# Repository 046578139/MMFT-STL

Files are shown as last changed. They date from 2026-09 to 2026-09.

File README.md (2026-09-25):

# MMFT-STL

3D-printable models for **Mountain Maryland Firearms Training**.

## Pistol display stand

A counter-top display stand: a filleted base plate with a leaning
magazine-well blade at one end and the MMFT mark standing proud of the plate
in front of it. Designed to print in a black body with the mark in red.

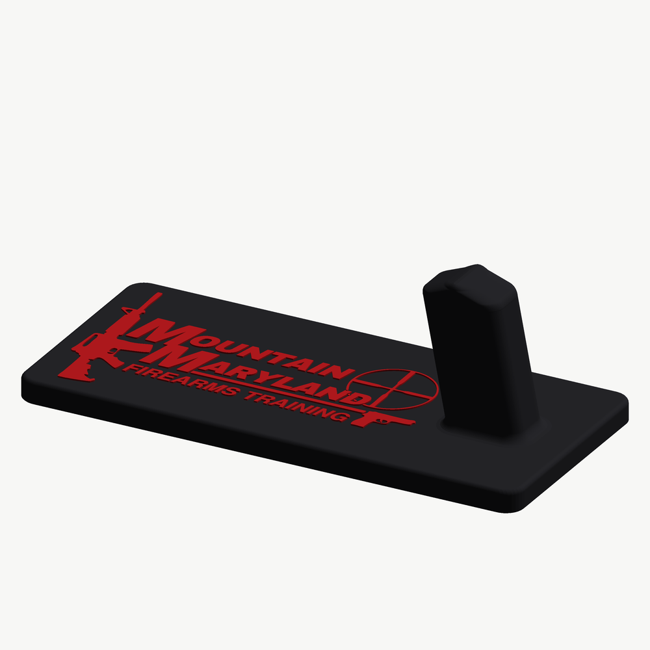
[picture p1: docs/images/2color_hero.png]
The stand in black with a red mark


| | |
|---|---|
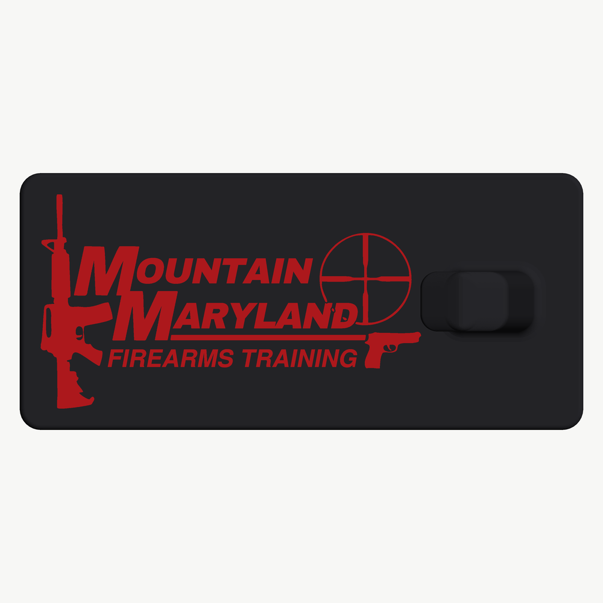
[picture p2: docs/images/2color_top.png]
top
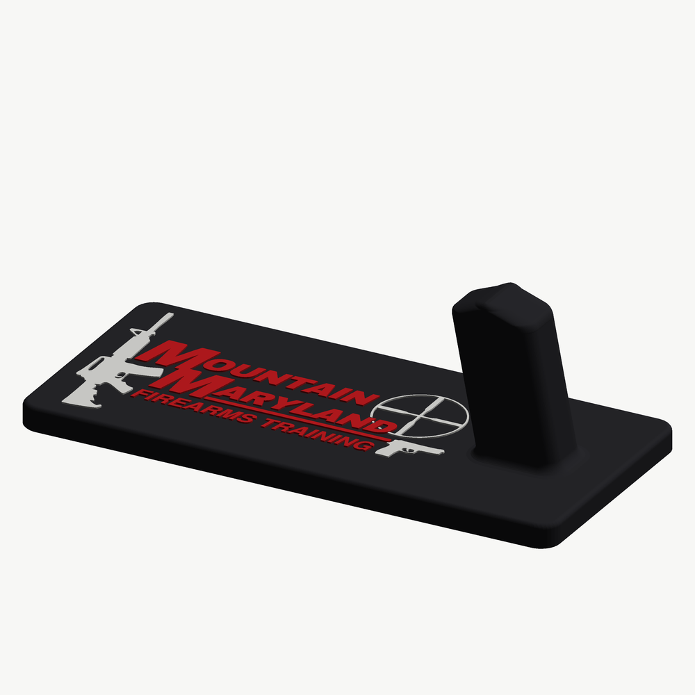
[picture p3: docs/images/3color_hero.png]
three colour
|  |  |
| Two colours — black and red | Three colours — see note below on which way round |

**215 × 98 × 70.6 mm.** No supports, no bridging, flat on the plate.

Sized up from an earlier 160 × 70 after a test print: at that size the gaps
*between* the letters were narrower than a nozzle could lay a bead into, so
they filled in and the lettering came out ragged. The mark is now 145 mm
wide instead of 90, and the narrowest gap in it is 0.460 mm.

**Print it with a 0.4 mm nozzle.** That number is why: a 0.6 mm nozzle lays
a bead wider than the gap and fuses four separate pieces of the mark into
one blob, and no slicer setting can undo it.

One thing to know before these go on a counter: the stand is enormously
stronger than it needs to be, but it tips sideways at about 0.65 lbf, and
**infill does not fix that** — see
[Will it stay put](docs/PRINTING.md#will-it-stay-put).

### Raised or flush

The mark comes two ways. Both look the same from straight on; they differ
in whether it stands on the plate or is let into it.

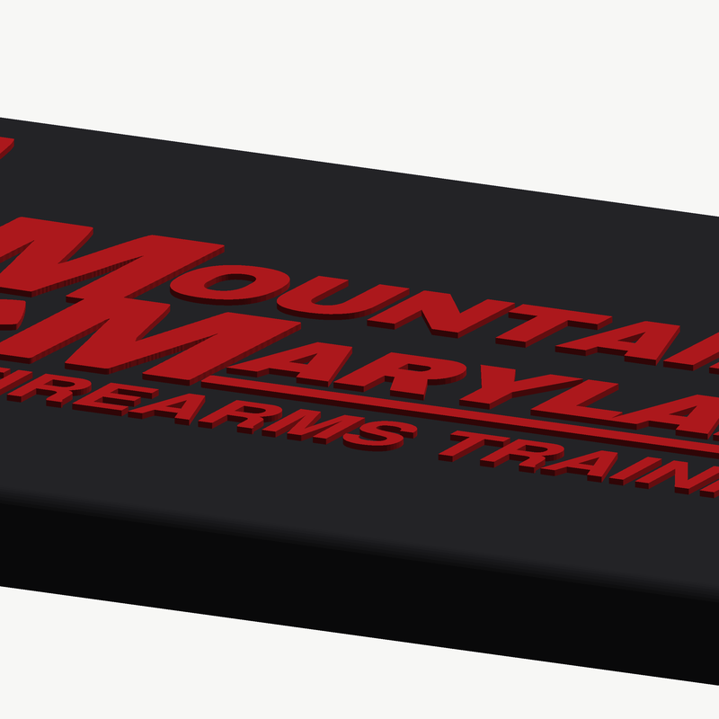
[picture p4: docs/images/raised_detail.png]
raised
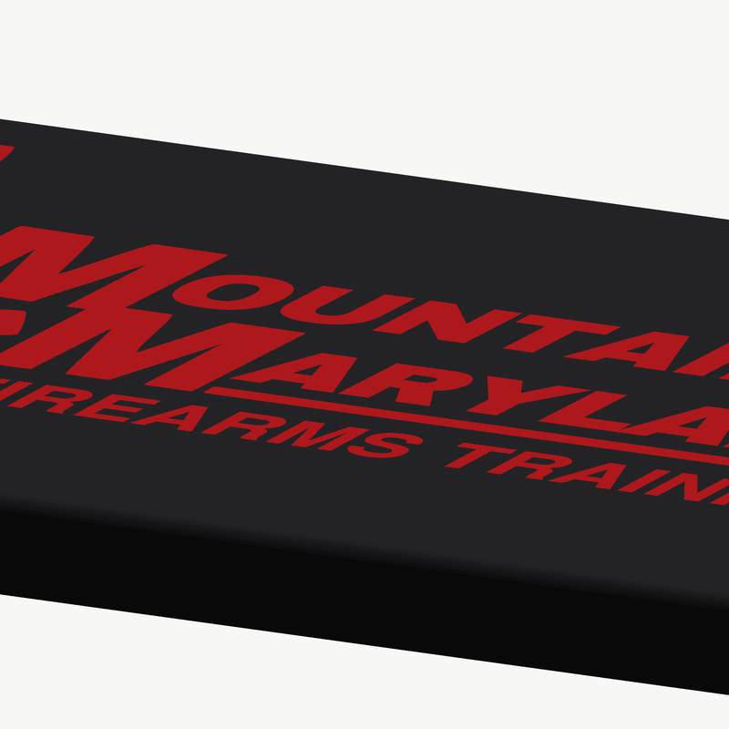
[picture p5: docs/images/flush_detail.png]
flush
|  |  |
|---|---|
| **`stl/raised/`** — stands 0.6 mm proud | **`stl/flush/`** — let 0.6 mm into the plate |

**Flush is the one to print for a shop counter.** Nothing stands above the
surface to be caught or chipped, and every piece of the mark is boxed in on
all four sides by the black around it — a muzzle dragged across it just
slides. It needs a multi-material printer, because black and red share the
same three layers.

**Raised** is there because it prints in two colours on *any* printer. Every
layer above the plate is mark and nothing else, so a single extruder only
needs a filament change at Z = 9.6 mm and another at Z = 10.2 mm. The
trade-off is that two pieces are small — the slivers of the scope's
crosshair showing through "ND", at 0.71 and 1.02 mm², which is not much
holding a 0.6 mm tall nub. Everything else is far sturdier since the mark
was scaled up; the smallest piece of lettering is now 9.6 mm².

### One file, or several

**`3mf/` holds the whole model as a single file per variant** — parts kept
together, colours already set, nothing to line up. Open one and print:

| File | Parts |
|---|---|
| `3mf/MMFT_Stand_flush_2color.3mf` | black body + red mark |
| `3mf/MMFT_Stand_flush_3color.3mf` | black body + red lettering + bone firearms |
| `3mf/MMFT_Stand_raised_2color.3mf` | black body + red mark |
| `3mf/MMFT_Stand_raised_3color.3mf` | black body + red lettering + bone firearms |

**This cannot be done as an STL.** An STL file is a bare list of triangles
with no notion of colour, material, or even where one body ends and the next
begins — so a two-colour model has to travel as two STLs and be lined up
again at the other end. 3MF is the format that fixes exactly that, and every
current slicer reads it. As a bonus the whole two-colour project is 0.65 MB
against 3.4 MB for the equivalent pair of STLs.

Inside, the parts are written as *components of one object* rather than as
separate objects side by side. That matters: as separate objects a slicer is
free to move them independently, and a single auto-arrange would slide the
mark off the plate it belongs to. As components they move together and
cannot come apart.

Colours are carried twice — `<basematerials>`, which is the core 3MF way any
slicer reads, and `Metadata/model_settings.config`, the Bambu Studio and
Orca convention where each part names the filament slot it wants. If your
slicer understands neither, you still get the geometry and the separate
parts, and assigning the filaments by hand is a couple of clicks.

Bambu Studio greets any non-Bambu 3MF with *"The 3mf file has invalid
config, load geometry data only"*. That is about the print profile, not the
model, and these files carry no print profile on purpose — see
[docs/PRINTING.md](docs/PRINTING.md).

### STL files

Still here for anything that will not take a 3MF, and for single-colour
prints where one body is all you need.

| File | Colour | Set |
|---|---|---|
| `raised/MMFT_Stand_black_body.stl` | black | 2- and 3-colour |
| `raised/MMFT_Stand_red_logo_full.stl` | red | 2-colour |
| `raised/MMFT_Stand_red_logo_text.stl` | the lettering | 3-colour |
| `raised/MMFT_Stand_light_logo_art.stl` | the firearms | 3-colour |
| `raised/MMFT_Stand_one_piece.stl` | any single colour | on its own |
| `flush/MMFT_Stand_black_body.stl` | black | 2- and 3-colour |
| `flush/MMFT_Stand_red_logo_full.stl` | red | 2-colour |
| `flush/MMFT_Stand_red_logo_text.stl` | the lettering | 3-colour |
| `flush/MMFT_Stand_light_logo_art.stl` | the firearms | 3-colour |
| `flush/MMFT_Stand_engraved_one_piece.stl` | any single colour | on its own |

Every part is modelled in the same coordinate space, so a multi-material
slicer only needs them loaded together and assigned colours — there is
nothing to line up by hand. The flush body and its inlay reassemble into the
solid plate to within a hundred-thousandth of a cubic millimetre, with no
overlap for a slicer to argue with.

`flush/MMFT_Stand_engraved_one_piece.stl` is the flush plate with its
pockets left empty — one colour, nothing proud of the surface at all. The
engraved channels are comfortably printable (the thinnest is 1.72 mm); what
is marginal is the ribs of plate left standing *between* them, the narrowest
of which is 0.46 mm — about one bead wide, so a few will look soft. The
lettering comes through cleanly.

See [docs/PRINTING.md](docs/PRINTING.md) for settings and filament choice.

### How crisp is the mark?

It is traced as vector outlines, not stamped from pixels — straight edges
come out exactly straight (the rule under the wordmark is two points across
46 mm) and the scope ring is round to 0.026 mm RMS, about a fifteenth of an
extrusion width. Nothing in the geometry is stepped.

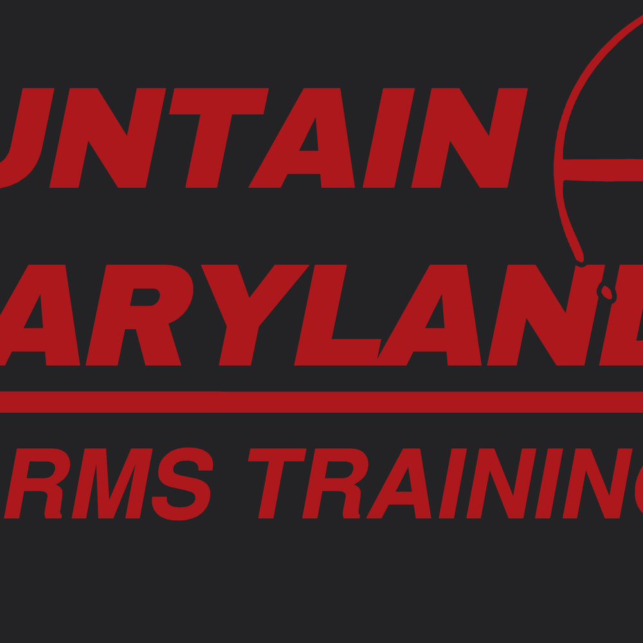
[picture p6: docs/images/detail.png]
detail


The preview images are rendered at a size where one pixel is roughly 0.2 mm
of real part, so curves in them can look stepped when the model is not.
`src/preview.py` supersamples to keep that under control.

### The lettering

Two runs in the mark are too small in the source to trace well, for a
reason no amount of work on the tracer can fix. "FIREARMS TRAINING" is
about **34 px** of cap height in the file, and the small caps of the
wordmark about **47 px**. There is no detail there to recover.

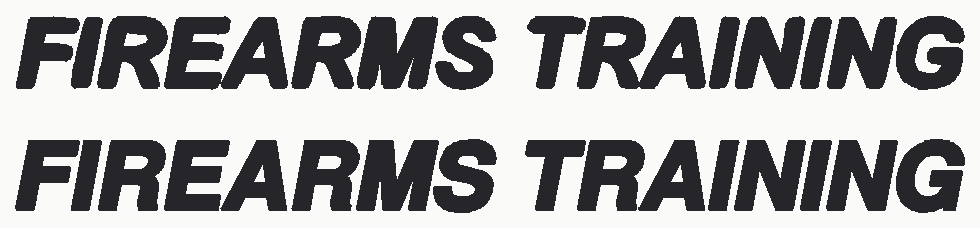
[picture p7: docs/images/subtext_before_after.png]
sub-text, before and after


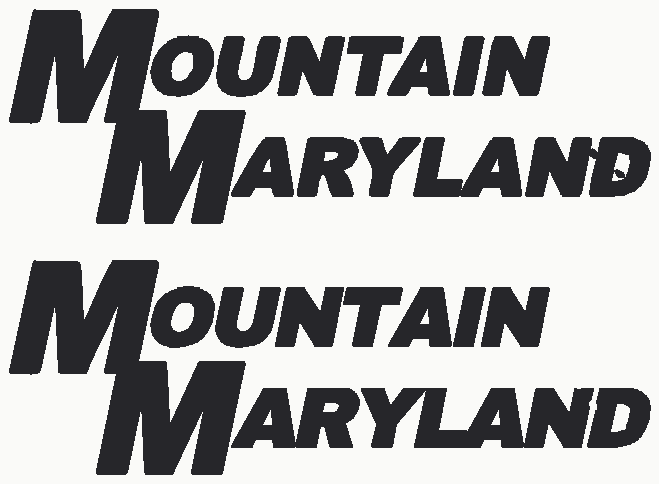
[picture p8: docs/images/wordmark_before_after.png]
wordmark, before and after


*Each pair: traced from the raster, then set from type.*

Both are re-set from outlines instead. Each run was matched the same way —
normalise cap height, solve tracking to match the run's width, score pixel
overlap against the source — then fitted to the box the traced run
occupied, so everything lands where the artwork puts it.

**They are not the same typeface, and that turns out to be the point.**
Stroke-to-cap comes out at 0.176 for the sub-text and 0.265 for the
wordmark: the mark pairs a Bold with a Black. Setting both in one weight
would have flattened that, so each is matched on its own.

| Run | Candidate | Overlap |
|---|---|---|
| Sub-text | **FreeSans Bold Oblique** (Helvetica clone) | **0.871** |
| | Nimbus Sans Bold Italic (Helvetica clone) | 0.870 |
| | Arial metrics (Liberation Sans Bold Italic) | 0.791 |
| Wordmark | **Archivo Black**, condensed 3 % | **0.895** |
| | Archivo weight 900 | 0.870 |
| | Asap weight 900 | 0.865 |
| | any Bold weight | below 0.69 |

The sub-text is Helvetica, near enough. The wordmark is a heavy grotesque
that Archivo Black stands in for: every letter traces 4–7 % narrower than
Archivo draws it, so the original is the narrower face of the two, and
condensing Archivo by 3 % both improves the match and brings the tracking
needed to fill the line back near zero, where the letters stop colliding.

Weight is preserved in both — the sub-text comes out at 1.08 mm median
stroke against the traced 1.05 mm. Only the edges change.

**The two large M's are left as traced.** They are 177 px in the source,
clean enough that setting them would gain nothing, and they are a drawn
lockup rather than two letters set side by side — re-setting them would
have broken the way they interlock.

**If you have the original vector logo** (`.ai`, `.eps`, `.svg` or a vector
`.pdf`), that would beat all of this — send it over and the whole mark can
come from it rather than from a 720 px raster.

### Where the ink/paper boundary is taken

Tracing needs a level at which a grey anti-aliased pixel stops counting as
paper and starts counting as ink. The obvious choice is halfway, and
halfway is wrong for this artwork: it cuts through the middle of the
anti-aliasing and the thinnest closed shapes come apart. The pistol's
trigger guard breaks at the bottom, its opening drains into the
background, and what should be a clean loop prints as a hook with the plate
colour flooding into it. One of the rifle's counters goes the same way.

The level is `ink_level` in `src/logo.py` and sits at **0.70**. That holds
both guards closed for about 4 % more ink overall, and closing them costs
nothing in printability — every gap in the mark still clears a 0.4 mm
nozzle, and the recovered guard opening is 2.1 mm across.

### One thing the re-setting fixed

The scope's crosshair shows through two gaps in "ND", and the artwork holds
it off the letters with a thin white halo. Those two slivers — 0.21 and
0.32 mm² — sit in the wordmark's band, so grouping by position had been
filing them with the lettering. In the three-colour set that meant printing
them red instead of with the rest of the optic. They are now grouped with
the scope, and the re-set letters are cut back by the same 0.35 mm halo the
artwork uses, so the crosshair still reads as passing in front of them.

### Regenerating

The models are generated, not hand-modelled — every dimension is a named
constant near the top of `src/build.py`, and the mark is traced from
`assets/mmft_logo.png` at build time. Change the plate size, move the mark,
swap the artwork, and rebuild:

```sh
pip install -r requirements.txt
python src/build.py      # writes stl/
python src/preview.py    # writes docs/images/
```

| Module | What it does |
|---|---|
| `src/build.py` | Dimensions, the stand, and the exported part sets |
| `src/logo.py` | Traces the logo raster into polygons, splits it into its parts |
| `src/geometry.py` | Rounded rectangles, lofts, extrusions, booleans |
| `src/preview.py` | Renders the images in `docs/images` |

### About the blade

The blade's dimensions are carried over from a Glock-branded stand supplied
as the starting point for this design, so anything that fitted that one fits
this: a 33.67 × 22.84 mm rounded-rectangle section with 6.5 mm corners,
leaning 10.89°, standing 61.1 mm clear of the plate, with a chisel-shaped
lead-in at the tip. The root fillet is opened up from 3.57 mm to 4 mm for
strength. The plate around it and the mark on it are new work, written from
scratch in `src/` — no part of the original mesh is redistributed here.

> If that original model carried a licence, it is worth checking before
> selling prints of this one. The blade section is a functional dimension
> rather than creative expression, but we did take it from somewhere.

### Sizing it to a different pistol

The post stands in for a magazine — it is drawn to the section of one, which
is why it fits a Glock and not a single-stack 1911 or a 2011. Everything
else about the stand is independent of the platform, so a variant is just a
different post on the same base.

`BLADE_NOMINAL_W` and `BLADE_NOMINAL_D` in `src/build.py` are the section as
the magazine well sees it, and `BLADE_RISE` is how far the post stands above
the plate. Change those three and rebuild.

To find out what they should be for a given pistol, print the fit gauge and
try it in the real thing. `stl/gauge/platforms/` holds ten stubs aimed at
specific pistols — Glock, P320, 1911 and brackets for the 2011 family and
the other double stacks; `stl/gauge/` holds a plain size grid for anything
those miss. See [docs/FITTING.md](docs/FITTING.md), which also lists the
magazine sections that could actually be sourced.

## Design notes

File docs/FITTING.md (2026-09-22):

# Fitting the post to a platform

The post on this stand is shaped like a magazine, because that is what it
stands in for — it goes up into the magazine well and holds the pistol the
way a seated magazine would. A measured Glock 17 magazine is 33.1 × 22.8 mm
and the post presents 33.06 × 22.84 mm, so it fits a Glock and very little
else. A single-stack 1911 well is far narrower; a 2011 or a wide double
stack is wider again.

Everything about the stand except the post is independent of the platform,
so a variant is just a different post on the same base. What is missing is
the number to draw it to, and that is what the gauge is for.

## Why a gauge rather than a caliper

Measuring a magazine gets you the magazine, not the well. It misses the
flare at the mouth, how far the well actually runs before something stops
the magazine, and how much clearance still feels secure rather than tight.
Trying a shaped post in the real pistol answers all three at once, and the
gauge then serves every platform you add later.

## Known sections

What could actually be sourced. All of these are caliper readings posted by
people who own the magazines, not manufacturer specifications — treat them
as good starting points, not gospel.

| Platform | Long axis | Thin axis | Source |
|---|---|---|---|
| Glock 9 mm — 17/19/26/34/45 | 33.1 mm | 22.8 mm | [Glock Talk](https://www.glocktalk.com/threads/glock-17-9mm-and-40-mag-dimensions.1669367/) |
| Sig P320 9 mm / .40 / .357 | ~31.4 mm | ~21.6 mm | [SIGforum](https://sigforum.com/eve/forums/a/tpc/f/430601935/m/7630051774) |
| Sig P227 .45 | ~34.9 mm | ~23.8 mm | [SIGforum](https://sigforum.com/eve/forums/a/tpc/f/430601935/m/7630051774) |
| 1911 single stack .45 | 34.8 mm | 13.7 mm | [Pistol Smith](https://www.pistolsmith.com/threads/1911-magazine-dimensions.21328/) |
| 2011 — Staccato, Atlas, Infinity, Prodigy | — | — | none found |
| Sig P226, S&W M&P, FN 509 | — | — | none found |

Two things fall out of that table. The platforms really are distinct — a
Glock post is 1.7 mm too long for a P320 well and 9 mm too thick for a
1911 — and the spread is wider than it looks, because single stacks are
barely half the thickness of a double stack.

Cartridge length sets a floor nobody can go under: 9 mm Luger is 29.69 mm
overall, .40 S&W 28.88, .45 ACP 32.39, .38 Super 32.0. A magazine body has
to be roughly 2.5 mm longer than the round it holds, so **no centrefire
pistol magazine is much under 31 mm in its long axis**, and a .45 cannot
be under about 35. If something is binding below that, it is not the long
axis doing it.

## Two sets of stubs

**`stl/gauge/platforms/`** — ten stubs aimed at specific pistols, each
labelled with the platform on the first line and its section on the second.
Start here.

| Stub | Section | What it is |
|---|---|---|
| `GLOCK` | 33.1 × 22.8 | Glock 9 mm; one post covers 17/19/26/34/45 |
| `P320` | 31.4 × 21.6 | Sig P320, 9 mm / .40 / .357 |
| `1911` | 34.8 × 13.7 | 1911 single stack |
| `1911-S` | 34.2 × 12.9 | 1911, one size under |
| `1911-L` | 35.4 × 14.6 | 1911, one size over |
| `2011-A` | 34.0 × 21.0 | 2011 family, bracketed |
| `2011-B` | 35.0 × 22.5 | 2011 family, bracketed |
| `2011-C` | 35.8 × 24.0 | 2011 family, bracketed |
| `DS-A` | 32.5 × 23.5 | P226 / M&P / FN, bracketed |
| `DS-B` | 34.0 × 25.0 | P226 / M&P / FN, bracketed |

The three sourced sections are drawn at the figure as measured. The
bracketed ones are guesses spread across the plausible range, because no
measurement could be found — if none of a bracket fits, say which way it
missed and the next set can be aimed properly.

**`stl/gauge/`** — the original twelve, a plain grid of 30/32/34 against
16/19/22/25. Its range was wrong for single stacks: nothing in it is
thinner than 16 mm, so no 1911 was ever going to take one, and at 34 mm
its longest is shorter than a .45 magazine. It is still useful for
anything the platform set brackets badly.

## Printing it

`stl/gauge/MMFT_FitGauge_all.stl` is all twelve on one plate, 146 × 220 mm.
The individual stubs are beside it if you would rather print a few at a
time.

These only need their outside surface, so print them **hollow — two walls,
0 % infill**. As solids they come to 286 cm³; hollow they are a fraction of
that. Any nozzle and layer height will do; nothing here is fine detail.

## Using it

Work with the pistol cleared and the magazine out, the same as you would
for any dry function check.

Twelve stubs cover 30, 32 and 34 mm front-to-back against 16, 19, 22 and
25 mm side-to-side. Each is labelled with its own size on the flange.

Start small and work up. You are looking for **the largest stub that seats
without being forced** — it should go in under its own weight or close to
it, and hold the pistol without slop. If you have to push, it is too big;
if the pistol rocks on it, go up a size.

The ticks up one narrow face are every 5 mm, with a longer tick every
10 mm. If a stub bottoms out before it is all the way in, read off the tick
sitting at the mouth of the well — that is how deep the well runs, and it
sets how tall the post can be.

## What to send back

Per pistol:

* which stub fitted best — the name is enough, `2011-B` or `GLOCK`
* whether it bottomed out, and at which tick if it did
* whether it felt snug, loose, or between two sizes
* if nothing fitted, **which way it missed** — too long, too short, too
  thick, too thin. That is the most useful thing you can tell me about a
  bracketed family.

Between two sizes is useful information, not a problem — the generator
takes any dimensions, not just the ones on the gauge, so `32.5 x 20.5` is
as easy to draw as `32 x 19`.

## What happens to those numbers

Report the gauge figure as it is. The stubs stand straight up, so their
section is the section the well sees. The post on the finished stand leans
10.9° and is *sheared* rather than tilted, so it has to be drawn wider by
1/cos(lean) to present the same section to the well. The generator applies
that itself — `BLADE_NOMINAL_W` and `BLADE_NOMINAL_D` in `src/build.py` are
the numbers you read off the gauge.

Expect the finished post to come out a few tenths under the stub that fit
best. A post that matches a magazine exactly is a magazine-tight fit, which
is more than a display needs; on a counter where pistols come off and on all
day, a little clearance means less wear on the well and easier one-handed
seating.

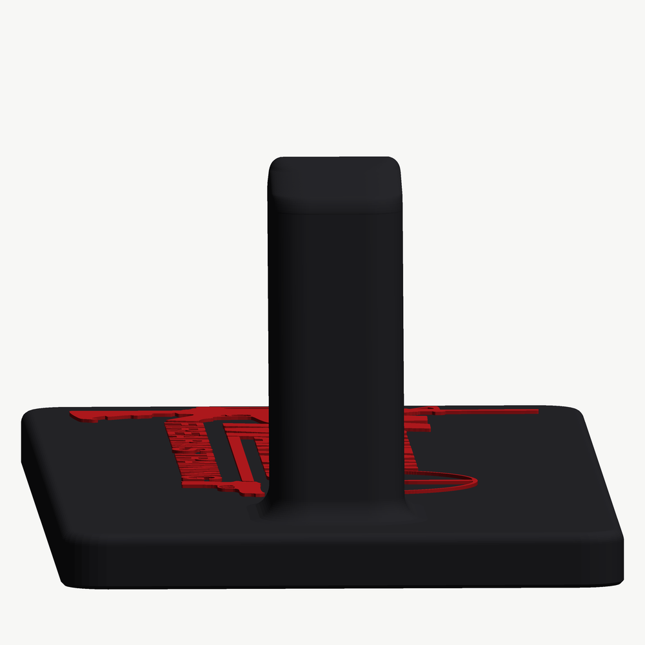
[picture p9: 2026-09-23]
docs/images/2color_side.png

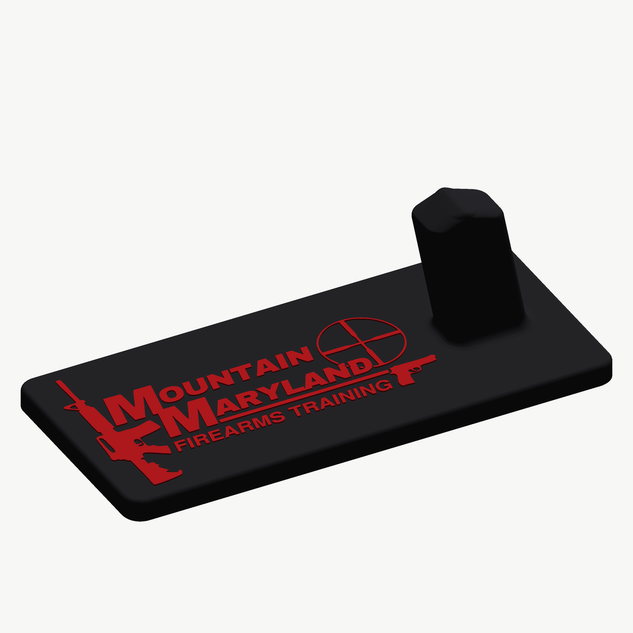
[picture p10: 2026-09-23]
docs/images/2color_iso.png

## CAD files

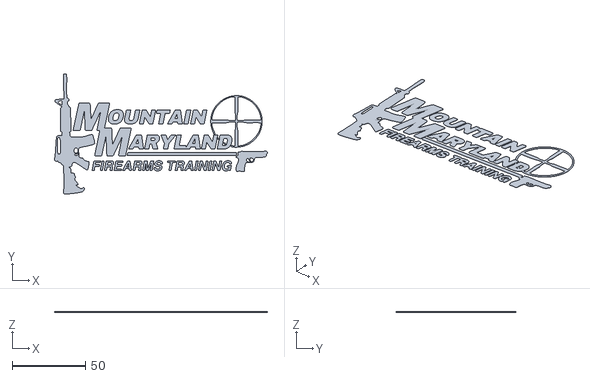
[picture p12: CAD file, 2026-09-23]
stl/flush/MMFT_Stand_red_logo_full.stl
145.1 x 81.7 x 0.6

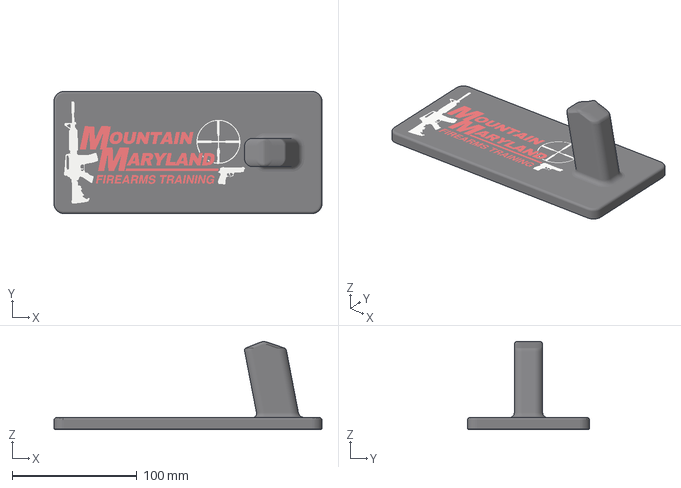
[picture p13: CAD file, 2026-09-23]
3mf/MMFT_Stand_flush_3color.3mf
215.0 x 98.0 x 70.6 mm

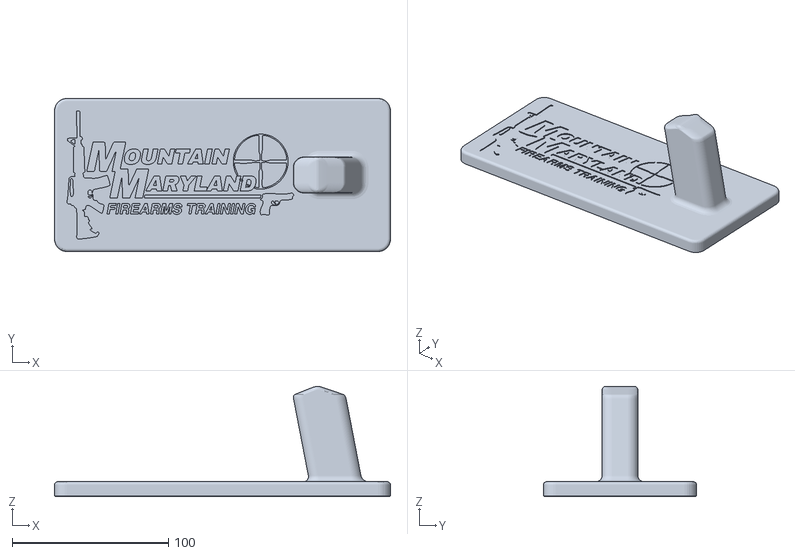
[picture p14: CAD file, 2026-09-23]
stl/flush/MMFT_Stand_engraved_one_piece.stl
215.0 x 98.0 x 70.6

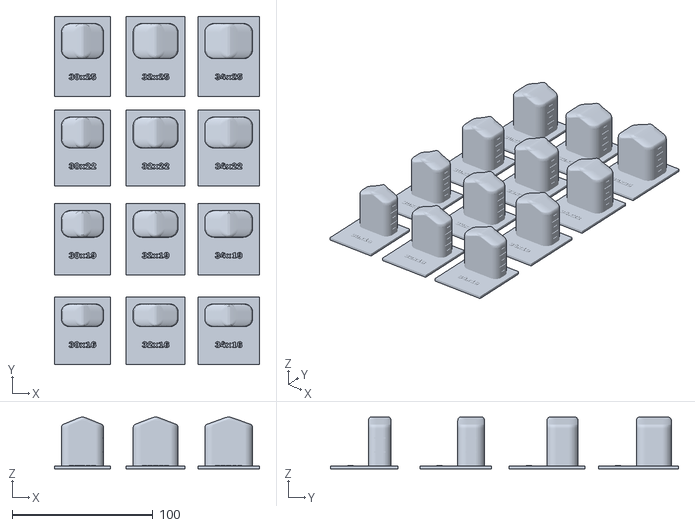
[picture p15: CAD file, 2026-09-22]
stl/gauge/MMFT_FitGauge_all.stl
146.0 x 247.5 x 36.9

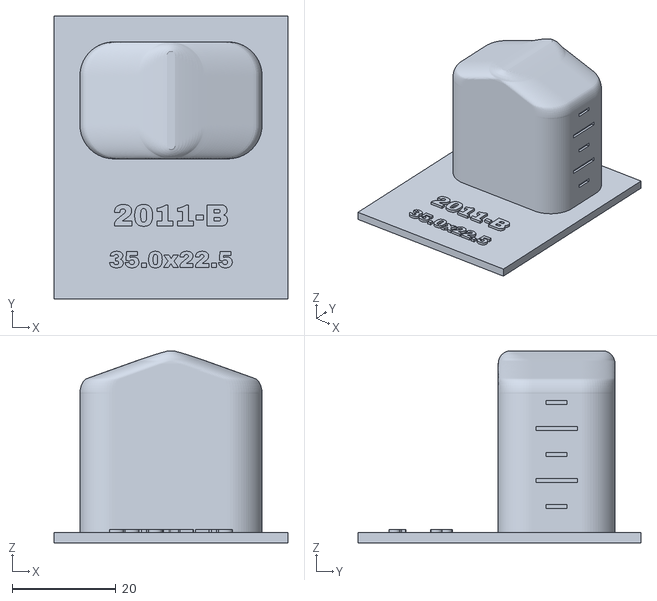
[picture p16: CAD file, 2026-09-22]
stl/gauge/platforms/MMFT_Fit_2011-B.stl
45.0 x 54.5 x 36.9

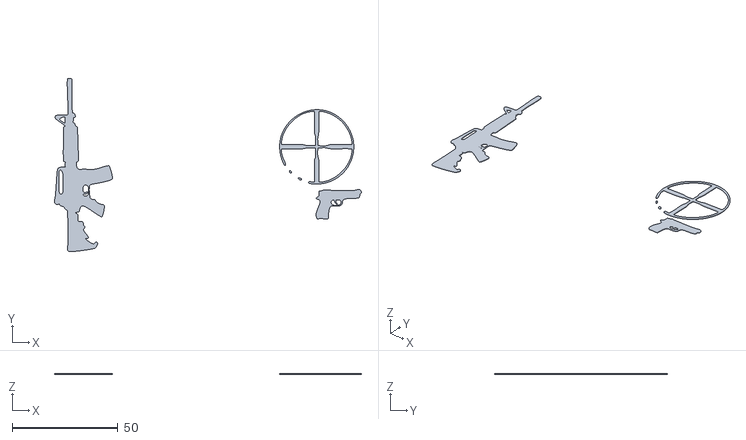
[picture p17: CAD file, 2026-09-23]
stl/raised/MMFT_Stand_light_logo_art.stl
145.1 x 81.7 x 0.6

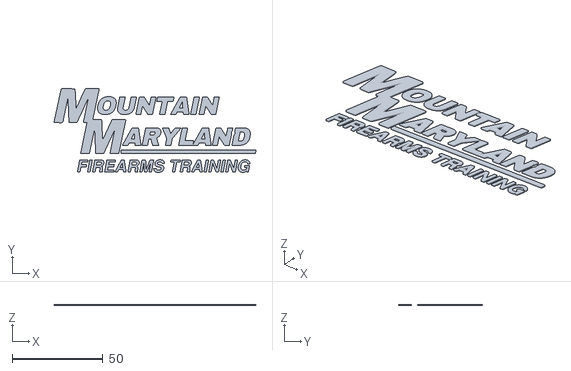
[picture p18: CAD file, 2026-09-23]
stl/flush/MMFT_Stand_red_logo_text.stl
111.4 x 46.3 x 0.6

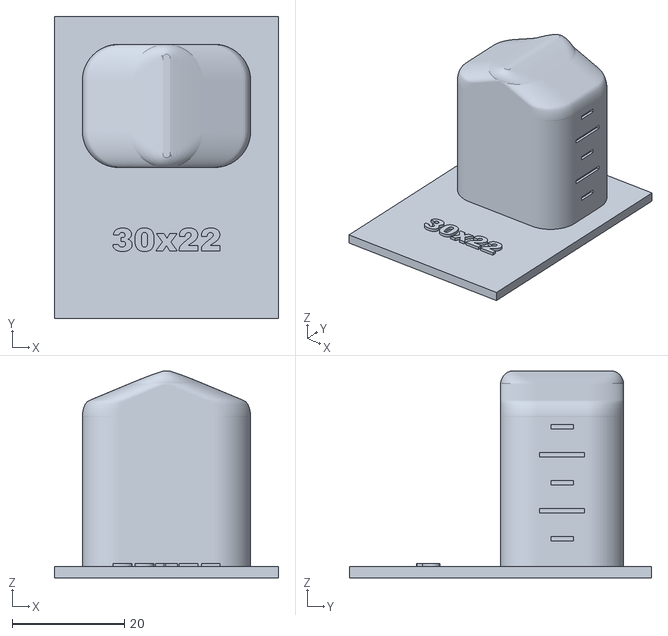
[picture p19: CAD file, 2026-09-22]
stl/gauge/MMFT_FitGauge_30x22.stl
40.0 x 54.0 x 36.9

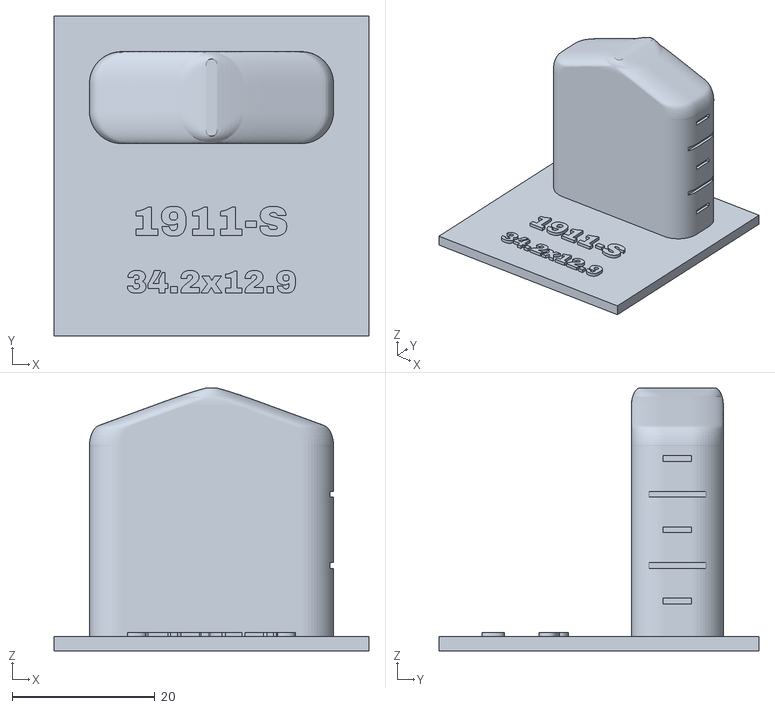
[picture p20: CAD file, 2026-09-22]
stl/gauge/platforms/MMFT_Fit_1911-S.stl
44.2 x 44.9 x 36.9

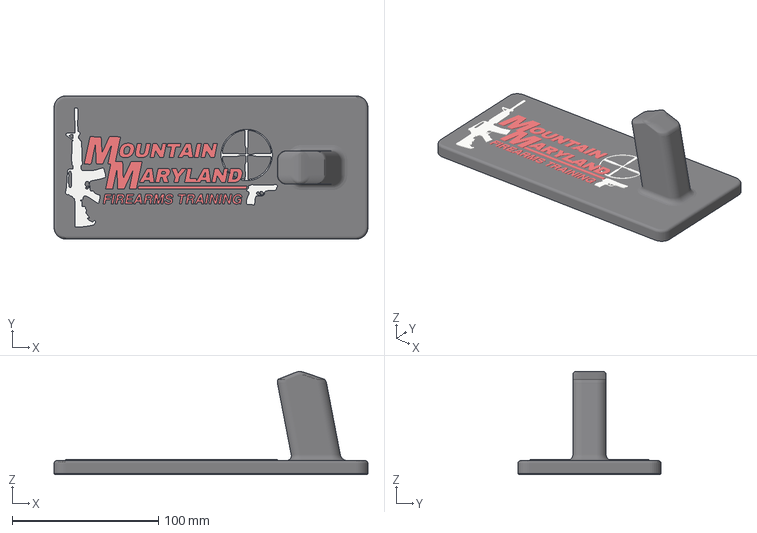
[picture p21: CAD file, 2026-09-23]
3mf/MMFT_Stand_raised_3color.3mf
215.0 x 98.0 x 70.6 mm

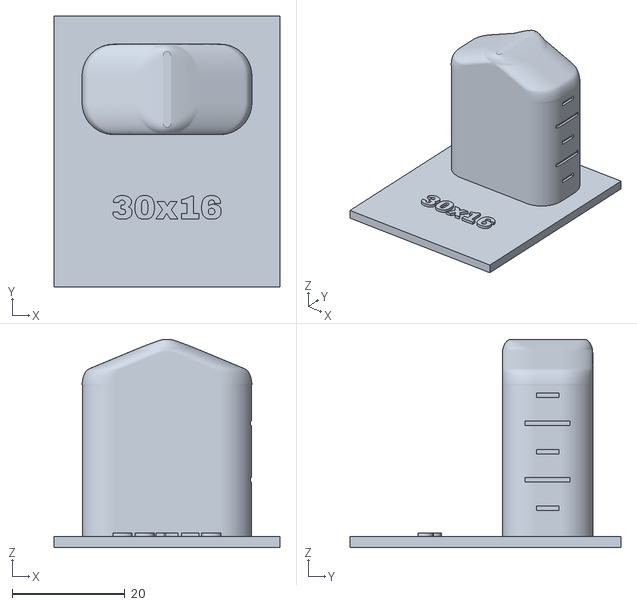
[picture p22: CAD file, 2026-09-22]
stl/gauge/MMFT_FitGauge_30x16.stl
40.0 x 48.0 x 36.9

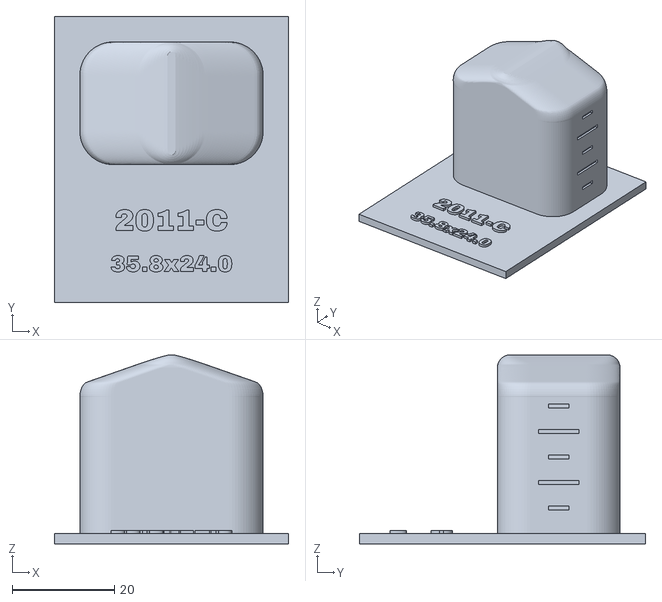
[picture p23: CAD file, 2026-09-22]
stl/gauge/platforms/MMFT_Fit_2011-C.stl
45.8 x 56.0 x 36.9

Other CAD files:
stl/raised/MMFT_Stand_red_logo_full.stl
3mf/MMFT_Stand_flush_2color.3mf
stl/raised/MMFT_Stand_one_piece.stl
stl/raised/MMFT_Stand_red_logo_text.stl
3mf/MMFT_Stand_raised_2color.3mf
stl/flush/MMFT_Stand_light_logo_art.stl
stl/gauge/MMFT_FitGauge_30x19.stl
stl/gauge/MMFT_FitGauge_30x25.stl
stl/gauge/MMFT_FitGauge_32x16.stl
stl/gauge/MMFT_FitGauge_32x19.stl
stl/gauge/MMFT_FitGauge_32x22.stl
stl/gauge/MMFT_FitGauge_32x25.stl
stl/gauge/MMFT_FitGauge_34x16.stl
stl/gauge/MMFT_FitGauge_34x19.stl
stl/gauge/MMFT_FitGauge_34x22.stl
stl/gauge/MMFT_FitGauge_34x25.stl
stl/gauge/platforms/MMFT_Fit_1911-L.stl
stl/gauge/platforms/MMFT_Fit_1911.stl
stl/gauge/platforms/MMFT_Fit_2011-A.stl
stl/gauge/platforms/MMFT_Fit_DS-A.stl
stl/gauge/platforms/MMFT_Fit_DS-B.stl
stl/gauge/platforms/MMFT_Fit_GLOCK.stl
stl/gauge/platforms/MMFT_Fit_P320.stl
stl/gauge/platforms/MMFT_Fit_platforms_all.stl
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

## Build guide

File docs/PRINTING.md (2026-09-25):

# Printing the stand

## On a Bambu Lab H2C

Open **`3mf/MMFT_Stand_flush_2color.3mf`** and print it in **Bambu PETG
Basic**, black and red.

That one file holds both parts, already positioned and already tagged with
the filament slot each wants, so there is nothing to import twice or line up
by hand. The `stl/flush/` set is the same model if you would rather load the
parts yourself.

**On PETG Basic rather than PETG HF.** HF was the recommendation here until
Bambu began phasing it out in every colour but black and brought back a
reformulated Basic in its place, so for a three-colour print HF may simply
not be available in red or white. Basic is the better choice regardless:
published figures put it ahead on flexural strength, layer adhesion and
impact, and it was reformulated specifically to string less and pick up
less moisture. Stringing is the one that matters on this model — the flush
inlay puts three colours inside the same three layers, so there are a lot
of tool changes happening right at the surface you end up looking at. What
you give up is HF's matte finish; Basic is glossier, which is a matter of
taste rather than a defect.

Either way, dry it first. PETG is hygroscopic and a damp spool strings
badly, which again lands on the visible face. The AMS 2 Pro is heated for
exactly this — a few hours in it before the print is enough.

Third-party PETG works too. You lose the RFID profile, so pick a generic
PETG profile and dry the spool yourself.

For the three-colour set, take the light colour from the same range as the
other two so all three behave identically on the plate.

**On purging, and why the flush inlay is nearly free on this machine.**
An earlier version of this note said that assigning all three colours to
one nozzle would make every colour change a real purge, and that they
needed spreading across nozzles. That is how a conventional AMS printer
behaves, and it is wrong for the H2C.

The H2C's right-hand side is the Vortek system: a rack of up to six
induction-heated hotends that the printhead physically swaps, heating each
one to temperature in about eight seconds. The left nozzle is a
conventional fixed hotend that cannot be changed mid-print. Each filament
gets its own dedicated hotend, so changing colour means stowing one hotend
and picking up another rather than pushing a new colour through the old
one. **Up to seven filaments — one on the left plus six on the Vortek rack
— print with no purge flushing at all.**

This print uses three. Whether they sit entirely on the right-hand AMS
units or are split across left and right makes no difference to waste:
three is comfortably under seven either way, so there is nothing to purge
and nothing to regroup. All three on the right is the simpler arrangement
and the one to use.

This is exactly why the flush inlay is the right choice here. On a
single-hotend printer it would be the expensive option — black and red
change over inside every one of the inlay's layers instead of twice for
the whole print. On the H2C those changes are hotend swaps, so the flush
version costs essentially nothing extra.

The one thing worth confirming in the preview is that the slicer really did
give each colour its own hotend rather than reusing one. If it has, the
prime tower will be small and there will be no flush volume between
colours.

The tightest thing in the mark is a 0.460 mm gap between two separate
shapes, and a 0.4 mm nozzle clears it by 0.06 mm — it works, but with very
little to spare. An obvious thought is to use the H2C's 0.2 mm hotend for
the two logo bodies and the 0.4 mm for the plate and post, which would give
those gaps better than twice the clearance they need.

**This is not possible, and the machine says so itself.** Bambu Studio's
Sync Nozzle dialog states plainly: *"Mixing nozzle diameters in one print is
not supported. If the selected size is only on one extruder, single-extruder
printing will be enforced."* Pick one diameter for the whole print.

That dialog also settles which diameter, because it reports how many of each
size the machine can reach on each extruder. On this printer, 0.2 mm is
available on the right extruder only — selecting it would force
single-extruder printing and **lose the multi-colour capability entirely**.
0.4 mm is available on both, so it is the only size that both renders the
mark and keeps the flush inlay possible.

### "The 3mf file has invalid config, load geometry data only"

Bambu Studio says this when you open one of these files. **It is expected,
and nothing is wrong.**

The message is about the *print profile* -- printer, nozzle, filament
settings -- not about the model. Bambu Studio shows it for any 3MF that is
not one of its own project files, which includes files out of Fusion,
Onshape, SolidWorks and everything else. These files deliberately carry no
print profile: guessing your printer and filament settings and quietly
overwriting your own would be worse than the notice.

Click OK. The geometry, the parts and their filament assignments all load.

**Worth a glance once you have:** the object list should show *MMFT Pistol
Stand* with two parts under it (or three, for the three-colour file), each
with its own filament number. If it does, everything came through and you
can slice.

If the filament numbers did not come through, it is two clicks -- right-click
each part and set its filament -- or load the matching `stl/` pair and assign
them there. The parts are in the same coordinate space either way, so
nothing needs lining up.

For the record, the packages are built to the specification: the reference
3MF library reads them with zero warnings, and the per-part filament slots
are written the way Bambu Studio's own importer expects (`<part>` matched to
its sub-object id, `subtype="normal_part"`, filament under a `<metadata
key="extruder">`).

## Which filament

For a stand that lives on a shop counter and has guns lifted off and
dropped back on all day, the answer is **PETG** — but for one reason, not
the two I would have guessed.

**Strength does not come into it.** Take the post as it actually prints —
hollow, six walls of 0.40 mm, ignoring the infill entirely — and its root
section modulus is 1663 mm³. Against PETG's roughly 45 MPa across its layer
lines, the post does not fail until something pushes **578 N (130 lbf)**
sideways at the slide. In PLA it is 450 N (101 lbf).

You will never see those numbers, because **the stand tips over at 2.9 N
(0.65 lbf)** — about 200× sooner. Every failure mode this design has is a
tipping problem, not a strength problem, and no filament choice or infill
percentage changes that. See *Will it stay put* below.

So infill in the base is neither structure **nor** useful ballast: going
from 15 % to 100 % adds 187 g and buys 25 % more tip resistance, which is
not worth having. Run 25 % and put the weight somewhere that works.

What is left is **heat**, and that one is real rather than theoretical.
PLA starts going soft around 55–60 °C. A dark part in a sunny window, in a
lit display case, or in a vehicle in July gets there easily. When it does
the post droops under a load it would otherwise ignore forever, and it does
not come back. PETG holds its shape to about 80 °C. That margin, plus
better UV stability over months of window light, is the whole case.

Impact matters a little as well — PLA is notch-sensitive where PETG bends
and springs back — but it is a second-order argument, not the main one.

**If the stands stay indoors, away from windows, and never travel in a hot
vehicle, PLA is a perfectly sound choice.** An impact-modified one beats
plain, and a matte finish suits a display piece. It renders the fine logo
detail marginally more crisply than PETG and is easier on a 215 mm flat
plate. The case for PETG is environmental, not structural.

**Whatever you pick, use the same material family for all three colours.**
PETG and PLA barely bond to one another, and on the flush inlay the colours
interlock inside the same three layers — a mixed print would leave the mark
sitting in its pocket with nothing holding it there.

PETG also keeps its colour under UV far longer than PLA, prints on any
machine without an enclosure, and comes in a good deep black and a strong
red from nearly every brand.

Its one real drawback is that it sticks *too* well to smooth PEI and glass.
Print on a textured plate, or put a thin layer of glue stick down as a
release agent, or you risk taking a chunk of the build surface with the
part.

### If not PETG

| Filament | When it makes sense | Watch out for |
|---|---|---|
| **ASA** | The display sits in direct sun. Best heat and UV resistance of the practical options. | Needs an enclosure; a 215 × 98 mm flat plate will lift at the corners without one. |
| **PCTG** | A tougher PETG, if your supplier carries it. Prints much the same. | Less widely stocked. |
| **PLA+ / Tough PLA** | Climate-controlled room, out of the sun, and you want the crispest possible lettering. | Still softens at ~60 °C. Plain PLA is too brittle here — if you go this route use an impact-modified one. |
| **ABS** | Only if it is what you already run in an enclosure. | Worse UV resistance than ASA, and the fumes. |

Skip the carbon-fibre filled versions. They are stiffer but more brittle,
they chew through brass nozzles, and the fibres dull the fine lettering.

## Settings

Two profiles below. The **display profile** is what to print now: the brief
is maximum quality and print time does not matter. The **batch profile** is
there for when you want a dozen of these and an overnight print each is too
much.

**On layer height, and a correction.** An earlier version of this document
claimed the layer height *had* to divide both 9.6 mm (the top of the plate)
and 0.6 mm (the inlay) exactly, and that 0.08 mm was therefore disqualified.
That was wrong, and the reason it is wrong tells you which presets are
actually safe: all of them.

The plate and the inlay are separate bodies, and a slicer cuts every body on
the *same* global Z planes. At any given layer, either the slice plane sits
below 9.0 mm and the plate is solid there, or it sits between 9.0 and 9.6 and
the inlay owns the logo region while the body's pocket excludes it. The two
are complementary at every layer no matter where the boundaries fall, so
**the inlay always fills its pocket exactly.** Divisibility changes the
inlay's layer *count*, not the fit — and seven layers of colour is as opaque
as five.

What actually varies with layer height is the finish on the 2 mm round-over
along the top edge of the plate, the one surface where the layers go nearly
horizontal and stair-stepping shows:

| Layer height | Round-over step | Step on the post's lean | Inlay layers |
|---|---|---|---|
| **0.08 mm** | **0.560 mm** | 0.015 mm | 7 |
| 0.12 mm | 0.682 mm | 0.023 mm | 5 |
| 0.16 mm | 0.784 mm | 0.031 mm | 4 |
| 0.20 mm | 0.872 mm | 0.039 mm | 3 |

The post's 10.9° lean is invisible at all of them. The round-over is where
the difference goes. On a Bambu H2C that makes **0.08mm High Quality** the
one to use here, with **0.12mm High Quality** giving most of the benefit
considerably faster.

| Setting | Display | Batch | Why |
|---|---|---|---|
| Nozzle | **0.4 mm** | 0.4 mm | Hard limit. See below — 0.6 mm cannot render this mark, and no amount of extra time fixes that. |
| Line width | **0.40 mm** | 0.42 mm | The narrowest gap in the mark is 0.460 mm. Staying under it is the whole game. |
| Layer height | **0.08 mm** | 0.20 mm | Finest H2C preset — best finish on the plate's top round-over. |
| First layer | 0.20 mm | 0.20 mm | Adhesion over a 215 mm footprint. |
| Walls | **6** | 4 | The post carries its load entirely in the walls. Also the post's surface *is* its walls. |
| Top solid | **1.2 mm** (15 layers) | 1.0 mm (5) | Specify it in millimetres, not layers. At 0.08 mm a preset's "5 top layers" is only 0.4 mm and will pillow over the infill. |
| Bottom solid | 0.8 mm (10 layers) | 0.8 mm (4) | |
| Infill | **25 %** gyroid | 25 % gyroid | Not structural and it does not help stability either — see below. 25 % is simply enough to hold the top surface flat. |
| Nozzle temp | 240–250 °C | 240–250 °C | High end of the PETG range, for layer adhesion at the blade root. |
| Bed | 70–80 °C | 70–80 °C | |
| Part cooling | 30–50 % | 30–50 % | Full blast weakens PETG layer bonding. |
| Outer wall speed | **25–30 mm/s** | 50 mm/s | The single biggest lever on visible surface quality, and where your unlimited time actually buys something. |
| Seam | **Scarf around entire wall** = on | same | *Not* a "Seam position" option — that dropdown only offers Nearest / Aligned / Back / Random. Scarf is the separate block of settings under it. This is the fix for the line up the post. |
| Wall generator | **Arachne** | Arachne | Classic lays fixed-width beads, so a 0.46 mm channel gets one 0.40 mm line and a 0.06 mm void. Arachne varies the width to fill it exactly. |
| X-Y contour / hole compensation | **0** | 0 | Leave alone. Any nonzero value eats directly into the 0.460 mm gaps. |
| Ironing | **Off** | Off | See the warning below — on the flush set it drags black into the red. |
| Supports | None | None | Nothing overhangs. The blade leans 10.9°, well inside what prints unsupported. |
| Brim | None | None | PETG needs no help here, and removing a brim from a 215 mm perimeter is worse than the problem. |
| Orientation | As exported, flat | As exported | Puts the layer lines where they do the most good. |

The solid model is 246 cm³. At 25 % infill expect roughly **150 g**; the
slicer will give you the real number.

**Do not turn ironing on for the flush set.** Ironing drags a hot nozzle
sideways across the finished top surface, and on the flush inlay black and
red *share* that surface. It will smear one into the other along every
boundary — which is every edge of the mark. If you want ironing, it is only
safe on the single-colour engraved version.

**Where the extra time actually goes.** Of the settings above, the ones that
change what you see are the layer height on the plate's 2 mm top round-over — not on the post's
lean, which is invisible at any of these — and the outer wall speed
everywhere.
Infill, walls beyond about four, and top layers beyond 1.2 mm cost hours and
change nothing visible.

### Why a 0.4 mm nozzle, and not 0.6

**It is the gaps, not the strokes.** This is worth being precise about,
because the obvious worry — that the lettering is too fine to print — turns
out not to be the problem at all.

Measured on the actual geometry, at the current 145 mm mark size:

| | |
|---|---|
| Ink in the mark | 3005 mm² across 36 separate shapes |
| Thinnest *whole shape* | 1.72 mm — nothing is delicate |
| Narrowest interior counter (the hole in an **A**, etc.) | 1.13 mm |
| Ink living in features narrower than 0.42 mm | **0.09 %** — tapered tips and corners only |
| **Narrowest gap between two separate shapes** | **0.460 mm** |

That last row is the one that decides the nozzle. Between the letters, and
between the lettering and the firearms, the plate has to show through a
channel 0.46 mm wide. A printer cannot lay a bead narrower than its nozzle,
so once the line width reaches 0.46 mm the two shapes either side stop being
separate and fuse into one blob.

| Line width | Shapes that fuse | Counters that close |
|---|---|---|
| 0.40 mm (0.4 nozzle, display profile) | **0** | **0** |
| 0.42 mm (0.4 nozzle, batch profile) | **0** | **0** |
| 0.45 mm | 0 | 0 |
| 0.50 mm | 4 | 0 |
| 0.62 mm (0.6 nozzle, stock) | **4** | 0 |
| 0.68 mm (0.6 nozzle, wide) | **5** | 0 |

A 0.4 mm nozzle clears the 0.46 mm limit with room to spare. A 0.6 mm nozzle
does not, and cannot be made to — this is what you were looking at when the
first test print came back with the gap between the **N** and the **T**
filled in. It was not a slicing setting and not a quality problem. The
nozzle was simply wider than the gap.

An earlier version of the model made this far worse. Every stroke was grown
0.15 mm per side so the finest details would survive, which worked, but
growing strokes *narrows the gaps between them by the same amount*. Scaling
the mark from 90 mm to 145 mm and cutting that growth to 0.05 mm fixed both
ends at once: the strokes got thicker in absolute terms and the gaps got
wider.

A finer nozzle for the logo alone is not an option: Bambu Studio refuses to
mix nozzle diameters within one print, and on this machine 0.2 mm exists on
the right extruder only, so choosing it would force single-extruder printing
and lose the flush inlay. 0.4 mm on both extruders is the configuration that
works. See the note under *On a Bambu Lab H2C* above.

### The line up one side of the post

That is the seam, not the model — every perimeter loop has to start and stop
somewhere, and with **Seam position** set to *Aligned* Bambu Studio stacks
them all at the same angle, so they form a line. There is only ever one seam
per loop, which is why the far side is smooth.

To fix it, do **not** look for a "Scarf joint" entry in the Seam position
dropdown; there isn't one — it offers only Nearest, Aligned, Back and
Random. Scarf is the separate block of checkboxes directly beneath it. Tick
**Scarf around entire wall**. The stock preset ships with *Smart scarf seam
application* already on, but "smart" only applies the scarf where the angle
threshold (155° by default) is met, which on a post this straight means
mostly nowhere. Forcing it around the entire wall ramps every loop's start
and end into a taper instead of a blob, and the line all but disappears.

Leaving Seam position on *Aligned* is then fine, and preferable — an aligned
scarf is consistent all the way up, where *Random* scatters the taper and
can read as noise on a large smooth flank.

The ridge over the *top* of the post is a different thing and is meant to be
there: it is the chisel-shaped lead-in, carried over from the stand this one
replaces.

## Raised or flush

Pick this first; it decides which folder you print from.

**`stl/flush/` — the mark is let 0.6 mm into the plate, sitting level with
it.** This is what to print for a shop counter. Nothing stands above the
surface, so there is nothing for a muzzle or a slide to catch, and each
piece of the mark is surrounded on all four sides by the black plate — to
move one you would have to break the plate. It needs a multi-material
printer: black and red occupy the same three layers.

**`stl/raised/` — the mark stands 0.6 mm proud.** Print this if you have a
single extruder, because it is the version that can be done with filament
changes. Everything above the top of the plate is mark and nothing else.

The reason the distinction matters is scale, though far less than it used
to. Since the mark was scaled up, the smallest piece of lettering has a
9.6 mm² footprint and the rifle alone has 1900 mm² — raised, none of that is
delicate. What is still small are the two slivers of the scope's crosshair
showing through the gaps in "ND", at 0.71 and 1.02 mm². Raised, those are
0.6 mm tall nubs held on by that much bonded area and loaded in peel if
something catches an edge. Nothing about that is unusual for a raised logo,
and plenty of parts live like that for years; it is simply a failure mode
the flush version does not have at all.

On a single-hotend printer the flush version costs more filament in purge —
black and red change over inside every one of the inlay's layers rather than
twice for the whole print, so budget a few extra cubic centimetres of waste.
**None of that applies to the H2C**, which swaps hotends instead of purging;
see *On purging* above.

## Getting the mark in red

### Multi-material printer (AMS, MMU, Palette, IDEX)

Load `MMFT_Stand_black_body.stl` and `MMFT_Stand_red_logo_full.stl` from the
folder you picked into one project, assign black and red, and slice. They
share a coordinate space, so they land in the right place with no alignment
step, and in the flush set the inlay fills its pocket exactly — no gap and
no overlap.

For three colours use `MMFT_Stand_black_body.stl`,
`MMFT_Stand_red_logo_text.stl` and `MMFT_Stand_light_logo_art.stl`.

**Which way round the two accent colours go is your choice, and the file
names are only the original suggestion.** The two bodies are just "the
lettering" and "the firearms"; whichever filament slot you point each at is
what it becomes.

The scheme in use is **white lettering with red firearms** on black, and it
is the better of the two. Red and black sit close together in luminance
even though they read as clearly different colours up close, so red
lettering on a black plate loses legibility at a distance. White against
black is the highest contrast available here, which puts the words where
they are readable across a room and leaves the red to work as an accent on
the rifle, scope and pistol — where drawing the eye is the whole point.

The file naming (`red_logo_text`, `light_logo_art`) predates that decision
and is kept so existing links and instructions stay valid.

Most of the filament a multi-material print wastes on this goes to purging
between black and red, not into the part — the mark itself is only 1 cm³.
Flushing into infill or into the object's own sparse regions cuts that down
a lot. Do not cut the flush volume too far on the flush set: black bleeding
into red shows up on the top surface, which is the surface you are looking
at.

### Single-extruder printer

This works because the mark stands proud of a flat plate, so everything
above the top of the plate is mark and nothing else.

Use the **`stl/raised/`** set for this.

1. Slice `raised/MMFT_Stand_one_piece.stl`.
2. Add a filament change at **Z = 9.6 mm** — the top of the plate.
3. Add a second one at **Z = 10.2 mm** — the top of the mark.
4. Load black, and swap to red and back when the printer pauses.

Place the changes by **Z height** in the slicer's preview rather than by
counting layers; a thicker first layer shifts the layer numbers but not the
heights.

* **Bambu Studio / Orca** — right-click the layer slider at that height,
  "Add filament change".
* **PrusaSlicer** — click the `+` on the layer slider at that height.
* **Cura** — Extensions → Post Processing → Modify G-Code → Filament Change,
  read the layer number off the preview at that Z.

Three colours cannot be done this way. The lettering and the
firearms sit in the same three layers, so that set needs a multi-material
printer.

### One colour

Two options, neither needing a filament change:

* `raised/MMFT_Stand_one_piece.stl` — the mark standing proud of the plate.
* `flush/MMFT_Stand_engraved_one_piece.stl` — the mark cut into the plate
  instead. Nothing proud of the surface at all, so it is the most durable
  thing here. The engraved channels are not the concern — the thinnest is
  1.72 mm — but the *ribs of plate left standing between them* are, and the
  narrowest of those is 0.46 mm, barely one bead wide. Expect a few of them
  to look soft. The lettering itself comes through cleanly, and this is the
  one version it is safe to iron.

## Will it stay put

Short answer: **it is far stronger than it needs to be and less stable than
I would want on a shop counter.** If you change one thing before putting
these out front, change the weight, not the infill.

All of the following is calculated from the actual model geometry — the
stand's real centre of mass at (118.9, 49.0, 10.7) mm — with a pistol
treated as a point mass on the post. Note that the post goes *up inside*
the magazine well, so the gun's mass sits low and does not perch on the tip.

It has not been measured on a finished print. Treat it as the right order of
magnitude and the right *ranking* of the options, not as three-significant-
figure truth. Every number here, and every feature width quoted above, is
reproduced by **`python src/analysis.py`**.

### The numbers

With a 625 g Glock 17 on it, at 25 % infill, pushing sideways at the slide:

| | Force to tip it |
|---|---|
| **Sideways, off the long edge** | **2.9 N — 0.65 lbf** |
| Backward, off the end behind the post | 3.6 N — 0.80 lbf |
| Forward, over the logo | 12 N — 2.7 lbf |

A heavier pistol helps a little, because the extra weight sits mostly low:
a SIG P226 goes to 4.2 N, a loaded Staccato 2011 to 4.7 N.

0.65 lbf is not much. It is a firm nudge with the back of your hand. The
geometry is simply against you — the plate is 98 mm wide with the post on
its centreline, so there is only 49 mm of lever holding up a pistol whose
mass sits around 100 mm in the air.

### Why infill is the wrong lever

This was the obvious thing to reach for and it does almost nothing:

| Infill | Stand mass | Sideways tip |
|---|---|---|
| 15 % | 126 g | 2.79 N |
| 25 % | 148 g | 2.87 N |
| 50 % | 203 g | 3.07 N |
| 100 % | 312 g | 3.48 N |

Going from 15 % to solid adds 187 g of filament and hours of print time to
move the number by a quarter. The reason is that infill adds mass *spread
through the whole part*, including the post, so it raises the centre of
mass almost as fast as it raises the weight.

### What does work

Mass low down. Ballast adds weight *and* drags the centre of mass toward
the plate, so it works on both terms at once:

| Ballast at plate level | Total weight | Sideways | Backward |
|---|---|---|---|
| none | 1.7 lb | 2.9 N | 3.6 N |
| +500 g | 2.8 lb | 4.7 N | 7.6 N |
| +1000 g | 3.9 lb | 6.6 N | 11.7 N |

Practical ways to get it there, roughly in order of how much I like them:

1. **Fasten the stand down.** If the display is a fixed shelf, two
   countersunk screws through the plate ends the conversation permanently
   and costs nothing. For a storefront this is usually the right answer.
2. **A steel plate bonded underneath.** 215 × 98 × 3 mm of steel is about
   500 g. Flat, invisible from the front, no model change needed.
3. **Lead tape or stick-on wheel weights** in the corners, if you would
   rather not commit to a full plate.
4. **A cast-in cavity** filled with shot or sand and capped. This is the
   tidiest result and the most work, and it needs a model change: a pocket
   opening downward cannot simply be bridged over a 70 mm span, so it would
   have to be a ribbed or cellular pocket with individually bridgeable
   cells, or a separate glued-on cap.

I have not made any of these changes to the model. Say the word and I will
add a ballast provision properly.

### The counterintuitive bit: do not use rubber feet

When something knocks the pistol, the stand can either **slide** — which is
harmless, the gun stays put and the stand scoots an inch — or **tip**, which
puts a firearm on the floor. Which one happens is decided by the friction
under it, and the grippier the feet, the more likely you get the bad one:

| Underside | Slides at | Verdict (no ballast, tips at 2.9 N) |
|---|---|---|
| Bare PETG on laminate | 2.3 N | **slides first** — gun stays on |
| Felt pads | 2.7 N | slides first, but only just |
| Cork | 4.2 N | **tips first** |
| Rubber / silicone feet | 6.1 N | **tips first** |

So the instinct to stick a rubber mat under a display stand is exactly
wrong here. Leave it on bare plastic or felt, and it fails safe. Add 500 g
of ballast and felt gets a comfortable margin again (slides at 4.4 N, tips
at 4.7 N) — but rubber is still the wrong choice even then.

### Strength, for completeness

None of the above is about the part breaking. Printed hollow with six
walls, the post does not fail until roughly **578 N (130 lbf)** pushes
sideways at the slide — about 200 times the force that tips the whole stand
over. You will never break one of these by using it.

## Before you print a batch

Print one and check the pistol actually sits on it. The blade section came
off the stand this design replaces and has not been tested here against a
real firearm. If it is tight, a few passes with sandpaper along the blade
sorts it out; if it is loose, raise `BLADE_HX` / `BLADE_HY` in
`src/build.py` by a few tenths and rebuild.

**Do not put rubber feet or a grippy mat under it.** That sounds backwards,
so see *Will it stay put* below — with this much height and this narrow a
base, high-grip feet convert a harmless slide into a topple. Felt or bare
plastic is the right answer unless you have added ballast.

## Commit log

2026-09-21 Add MMFT pistol display stand
    A counter-top display stand for Mountain Maryland Firearms Training:
    a filleted 160 x 70 x 10 mm base plate with a leaning magazine-well
    blade at one end and the MMFT mark standing 0.8 mm proud of the plate
    in front of it.
    The blade's dimensions are carried over from the Glock-branded stand
    supplied as the starting point, so anything that fitted that one fits
    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
    [MMFT_Stand_black_body.stl, MMFT_Stand_light_logo_art.stl, MMFT_Stand_one_piece.stl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]
2026-09-21 Add flush-inlay variant, antialias the previews
    Two sets now, under stl/raised and stl/flush.
    The flush set lets the mark 0.8 mm into the plate instead of standing it
    on top, so nothing is proud of the surface to catch a muzzle and every
    piece is boxed in on four sides by the black around it. The pocketed
    plate and its inlay reassemble into the solid plate to within 1.3e-5 mm3
    with zero overlap, so a multi-material slicer has nothing to resolve. It
    does need one, though -- black and red share the same four layers -- so
    the raised set stays for single-extruder printers, where two filament
    changes still do the job.
    The distinction is worth having because of the small pieces: the two
    accent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
    [MMFT_Stand_black_body.stl, MMFT_Stand_engraved_one_piece.stl, MMFT_Stand_light_logo_art.stl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]
2026-09-21 Re-set FIREARMS TRAINING from type instead of tracing it
    That line is about 34 px of cap height in the source image, so tracing it
    inherits every bit of that resolution: stems that should be straight come
    out wavy and the corners round off. No amount of work on the tracer
    recovers detail the file does not hold.
    Matching the source against a range of candidates -- normalising cap
    height, solving tracking to match the line's width, scoring pixel overlap
    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
    [MMFT_Stand_black_body.stl, MMFT_Stand_engraved_one_piece.stl, MMFT_Stand_one_piece.stl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]
2026-09-21 Refresh the close-up renders for the re-set sub-text
    These three supersample at 3-4x and were still running when the previous
    commit went in, so they carried the traced line. Same views, current
    geometry.
    Claude-Session: https://claude.ai/code/session_01Q9x41VAJD4Uzj6YT8CKYe6
2026-09-21 Re-set the wordmark's small caps, keep the M lockup as drawn
    The small caps of MOUNTAIN MARYLAND are about 47 px of cap height in the
    source -- better than the sub-text's 34 px, but still not enough to trace
    cleanly. They are now set from type the same way, matched per run and
    fitted to the box each traced run occupied.
    The wordmark is NOT the sub-text's face, and that is the point: stroke to
    cap comes out at 0.265 against the sub-text's 0.176, so the mark pairs a
    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
    [MMFT_Stand_black_body.stl, MMFT_Stand_engraved_one_piece.stl, MMFT_Stand_light_logo_art.stl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]
2026-09-21 Ship the model as 3MF projects: one file, parts and colours intact
    STL cannot do what was asked. An STL file is a bare list of triangles
    with no notion of colour, material, or even where one body ends and the
    next begins, so a two-colour model has to travel as two files and be
    lined up again at the other end. 3MF is the format that fixes exactly
    that, and every current slicer reads it.
    Four projects under 3mf/, one per variant: flush and raised, in two and
    three colours. The STL sets stay for anything that will not take a 3MF
    and for single-colour prints.
    The parts are written as components of a single object rather than as
    separate objects side by side. As separate objects a slicer is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
    [MMFT_Stand_flush_2color.3mf, MMFT_Stand_flush_3color.3mf, MMFT_Stand_raised_2color.3mf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]
2026-09-21 Document Bambu Studio's "invalid config" notice on the 3MF files
    Opening one of these in Bambu Studio raises "The 3mf file has invalid
    config, load geometry data only". Read against BambuStudio's own source
    it is about the print profile, not the model: Plater.cpp raises it from
    is_bbl_vendor_config()/check_project_config() over the DynamicPrintConfig
    that Metadata/project_settings.config would have supplied. These files
    carry no project_settings.config deliberately -- inventing printer and
    filament settings and quietly overwriting the user's own would be a worse
    outcome than the notice -- so every non-Bambu 3MF gets the same greeting.
    The model config itself is correct, checked against bb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
2026-09-22 Scale the stand up so a 0.4 mm nozzle can actually render the mark
    A test print showed the lettering coming out ragged with the plate colour
    missing from the gaps between letters. Three things, one of them mine.
    The first two were settings: printed on a 0.6 mm nozzle against a design
    aimed at 0.4, and at 0.30 mm layers, where the old 10.0 mm plate top,
    9.2 mm pocket floor and 0.8 mm inlay landed at 33.33, 30.67 and 2.67
    layers -- all three mid-layer.
    The third was the model. Every stroke was grown 0.15 mm per side so the
    finest details would survive a 0.4 mm nozzle, and that worked, but
    growing strokes narrows the gaps between them by the same amount. It
    left 21 channels a 0.4 mm nozzle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
    [MMFT_Stand_black_body.stl, MMFT_Stand_engraved_one_piece.stl, MMFT_Stand_flush_2color.3mf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]
2026-09-22 Add the magazine-well fit gauge, and quote the post section as nominal
    The post stands in for a magazine -- it is drawn to one's section, which
    is why it fits a Glock and not a single-stack 1911 or a 2011. A measured
    G17 magazine is 33.1 x 22.8 mm and the post presents 33.06 x 22.84.
    Everything else about the stand is independent of the platform, so a
    variant is just a different post on the same base; what was missing was
    the number to draw it to.
    Twelve labelled stubs under stl/gauge, spanning 30/32/34 mm front-to-back
    against 16/19/22/25 side-to-side, each with the lead-in the real post has
    so it enters a well the same way, and ticks every 5 mm up one narrow face
    to read how deep the wel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
    [MMFT_FitGauge_30x16.stl, MMFT_FitGauge_30x19.stl, MMFT_FitGauge_30x22.stl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]
2026-09-22 Add platform-named fit stubs, and fix the range the first gauge missed
    The first gauge came back with nothing fitting. Its range was wrong at
    both ends and the error was mine: I bracketed it around a Glock and never
    allowed for how thin a single stack is. Its thinnest stub is 16 mm and a
    1911 magazine is 13.7, so no 1911 could ever have taken one; its longest
    is 34 mm and a .45 magazine is 34.8, so it was short there too.
    Ten platform stubs under stl/gauge/platforms, labelled with the pistol on
    one line and the section on the other -- the section being the half worth
    reporting back if a stub turns out to fit something it was not named for.
    Three are drawn at measured figures: Glock 9 mm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
    [MMFT_FitGauge_30x16.stl, MMFT_FitGauge_30x19.stl, MMFT_FitGauge_30x22.stl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]
2026-09-22 Correct the filament reasoning: it is heat, not strength
    The earlier text led with brittleness and implied the post is working
    hard. It is not. Root section modulus is 4314 mm3 and a Glock 17 at the
    10.9 degree lean puts 0.118 N.m into it -- 0.028 MPa against roughly
    35 MPa for PLA across its layer lines, a safety factor near 1275. A
    steel-framed P226 makes it 0.037 MPa; five kilos of someone leaning on
    the post is 0.20 MPa and still 170x under. Strength does not separate any
    filament worth loading.
    PETG is still the recommendation, but for heat alone: PLA softens at
    55-60 C and a dark part in a window, a lit case or a summer vehicle gets
    there, at which point the post droops under a lo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
2026-09-23 Recommend PETG Basic over HF, and fix dimensions stale since the rescale
    Bambu is phasing PETG HF out in every colour but black and has brought
    back a reformulated PETG Basic, so a three-colour print may not be able
    to get HF in red or white at all. Basic is the better choice here
    regardless: published figures put it ahead on flexural strength, layer
    adhesion and impact, and it was reformulated to string less -- which is
    the property that matters on this model, since the flush inlay puts three
    colours inside the same three layers and every tool change lands near the
    visible surface. What it gives up is HF's matte finish.
    Also corrects numbers left behind when the stand was scaled up. The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
2026-09-23 Fix the trigger guards, lost to the ink/paper threshold
    Both the pistol's and the rifle's trigger guards printed as mush. Neither
    was a print problem: the guards were not in the geometry at all.
    Tracing needs a level at which a grey anti-aliased pixel stops counting as
    paper and starts counting as ink, and it sat at the obvious halfway point.
    Halfway is wrong for this artwork. It cuts through the middle of the
    anti-aliasing, and at this source's resolution the pistol's guard comes
    apart along its underside: the opening then drains into the background, so
    what should be a closed loop traced as an open hook with the plate colour
    flooding into it. The pistol polygon had zero interior rings.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
    [MMFT_Stand_black_body.stl, MMFT_Stand_engraved_one_piece.stl, MMFT_Stand_flush_2color.3mf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]
2026-09-25 Add the statics study, and a maximum-quality print profile
    The question was whether the stand is durable enough for a storefront and
    whether the infill percentage should change. It is not a strength problem
    and infill is the wrong lever, so both answers needed the numbers behind
    them. src/analysis.py reproduces every figure now quoted in the docs.
    Strength is a non-issue: printed hollow with six walls the post does not
    fail until 578 N (130 lbf) at the slide, roughly 200x the 2.9 N (0.65 lbf)
    that tips the whole stand over sideways. Tipping governs everything.
    Infill barely touches it -- 15% to solid adds 187 g and buys 25% more tip
    resistance, because infill raises the centre of mass n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
2026-09-25 Correct the layer-height claim: 0.08 mm is fine after all
    The previous commit called it non-negotiable that the layer height divide
    both 9.6 mm and 0.6 mm exactly, and disqualified 0.08 mm because the inlay
    lands at 7.5 layers. That reasoning does not hold.
    The plate and the inlay are separate bodies, and a slicer cuts every body
    on the same global Z planes. At any layer the slice plane is either below
    9.0 mm, where the plate is solid, or between 9.0 and 9.6, where the inlay
    owns the logo region and the body's pocket excludes it. The two are
    complementary at every layer wherever the boundaries land, so the inlay
    always fills its pocket exactly. Divisibility sets the inlay's layer
    count,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
2026-09-25 Fix the seam instruction, and call for Arachne
    "Set Seam position to Scarf joint" was wrong -- that dropdown offers only
    Nearest, Aligned, Back and Random. Scarf is a separate block of
    checkboxes beneath it, and the stock 0.08mm High Quality preset already
    has Smart scarf seam application on. But "smart" applies the scarf only
    where the 155 degree angle threshold is met, which on a post this straight
    is mostly nowhere, so the line survives. What actually fixes it is Scarf
    around entire wall. Seam position stays on Aligned; an aligned scarf is
    consistent up the post where Random scatters the taper.
    Also adds two rows the settings table was missing. Wall generator should
    be Arachne, not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
2026-09-25 Settle the 0.2 mm nozzle question: it is not possible
    The docs twice floated driving the logo bodies with the H2C's 0.2 mm
    hotend and the plate with the 0.4 mm, flagged both times as unverified.
    Bambu Studio's Sync Nozzle dialog answers it: "Mixing nozzle diameters in
    one print is not supported. If the selected size is only on one extruder,
    single-extruder printing will be enforced."
    The same dialog also settles which diameter to pick, by reporting per
    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
2026-09-25 Correct the purging advice for the H2C's Vortek system
    The note said that assigning all three colours to one nozzle would make
    every colour change a real purge, and told the reader to spread them
    across nozzles via Regroup filament. That describes a conventional AMS
    printer and is wrong for this machine.
    The H2C's right-hand side is the Vortek system: a rack of up to six
    induction-heated hotends the printhead physically swaps, each reaching
    temperature in about eight seconds, plus one conventional fixed hotend on
    the left. Every filament gets a dedicated hotend, so a colour change is a
    hotend swap rather than pushing new colour through the old nozzle, and up
    to seven filaments print with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
2026-09-25 Record the chosen three-colour scheme: white lettering, red firearms
    The two accent bodies were described throughout as "red lettering" and
    "bone firearms", which was only ever the first suggestion. The files are
    just "the lettering" and "the firearms" -- whichever filament slot each is
    pointed at is what it becomes -- so the docs now say that plainly rather
    than baking one scheme into the description.
    The scheme actually in use is white lettering with red firearms on black,
    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
